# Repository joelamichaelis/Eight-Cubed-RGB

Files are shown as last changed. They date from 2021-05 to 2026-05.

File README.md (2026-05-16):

# Custom 8x8x8 RGB LED Cube

Check out the companion repo: https://github.com/joelamichaelis/8x8x8_RGB_LED_CUBE
It appears that repo was made first.
It appears that I made this repo to try and migrate away from that once since it has a lot of messy firmware builds.

This repository contains my custom 8x8x8 RGB LED cube design/build, which I worked on from late 2018 through early 2020.
This is primarily intended as an archived engineering showcase of the custom hardware, PCB, and firmware work rather than as a polished build guide.

## Context

This is one of my first hobby electronics designs that I consider worth showcasing.

I stopped developing this project years ago. Prior to this 2026 documentation update, the repository contained only a standalone Keil firmware project with no other context.

The firmware is set up as a Keil MDK 5 project, exported from STM32CubeMX. I used Keil because it was the embedded development environment I was familiar with from college at the time. I like Keil, but in later projects, I have generally moved toward STM32CubeIDE and other completely free VS Code/GCC-based workflows. I have not migrated this repository.

The original RGB LED cube was built with a classmate for a one-semester, one-credit senior design class in Fall 2018, shortly before I graduated with my BSEE that December.

After graduating, I was left with a prototype-grade 8x8x8 RGB LED cube wired to prototype-grade electronics on protoboards and hastily connected to a rough Arduino sketch.

I wanted to keep developing the project, which led me to design custom electronics on a custom PCB, paired with custom STM32 firmware that I architected and wrote myself.

I named the custom PCBA the **motherboard** because it is the core electronics piece of the design. The motherboard combines the following circuitry onto a custom PCBA:

- Power supply
- LED power load switches
- STM32F103 Blue Pill microcontroller
- PWM drivers
- LCD
- Capacitive touch scroll wheel and keypad
- Unused ESP8266 RF module
- Supporting level-shifting circuitry

I wanted to gain real embedded system design experience, so I decided to move away from Arduino and use an STM32F103 on a Blue Pill microcontroller platform instead.

At the time, STM32F103 Blue Pill boards were abundant and inexpensive, around $20 for a 10-pack on eBay. The ones I used appeared to be genuine, or at least not poor-quality clones, which is different from what I observed after the COVID-era supply chain disruption.

## Physical Build

The physical build closely followed Steve Manley's RGB LED cube guides.

The key dependencies this project has from Steve's build are his mechanical build and assembly instructions, along with the cube's 9x9-inch base PCB.

The electronics, firmware implementation, and other design choices may have had some inspiration from Steve's and other people's designs, but my intent was to create my own design from scratch.

- Steve Manley's YouTube instructional series: https://www.youtube.com/playlist?app=desktop&list=PL2eohiNrVbjwBBmdMBNiG6VZEHkuPX1jt
- Steve Manley's Dropbox share, where his files and base PCBA have been made publicly available: https://www.dropbox.com/scl/fo/yy7fa9qwqz1qt9lec915d/ANIrxRMUm1n4fHg-VZvry4I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

This part of the project is not the highlight of this repository, but it is still worth documenting. Search the repository for supplemental photos.

My classmate created the mechanical jigs and helped with other parts of the build. I remember spending many nights and evenings bending and trimming individual LEDs with a jig, soldering those LEDs into 1x8 strips with bus wire using a second jig, and then soldering those 1x8 strips into 8x8 vertical panels with a third jig.

The 8x8 vertical panels were then soldered onto a base PCB we ordered. That base PCB adapts the cube's 192 soldered connections into 8 sets of 3x 1x8 header groupings.

Each TLC5940 current PWM driver used in this design controls 16 channels, so 12 daisy-chained PWM drivers map to all of the 1x8 headers.

## Motherboard

Our original senior design implementation required a jumbled mess of custom ribbon cables. The motherboard I designed eliminated the need for those ribbon cables and avoided having prototype electronics crammed under the cube.

Instead, the motherboard cleanly mates female 1x8 headers to the LED cube base's male 1x8 headers.

I also have some 3D-printed mechanical base parts that I intend to include in the repository if possible.

## Project Status / Known Issues

This project is in a functionally mature state with some known bugs, but it is no longer under active development.

Because this work was done several years ago, some files may be rough, incomplete, or not organized to the standard I would use for a current project. The goal of this repository is to preserve and share the project rather than present it as an actively maintained product or polished reference design.

I stopped developing the project after eventually getting bored, wanting to work on other things, or perhaps taking a break to move and then never taking the project out of its tub again.

I consider the core firmware driver and architecture logic to be architecturally mature.

I built a framework in the firmware to accept 3D video, but stopped short of creating a PC program or other tool that would allow animation files to be written and loaded via an SD card or other means.

I quickly learned that the STM32F103's 32K/64K flash was acceptable for simple, algorithmically defined animations, but inadequate for importing and running user-defined custom animations. This led me to realize that I should add an SD card to load and run externally defined animations, although I do not believe I fully developed that feature.

There is a Motherboard Rev2 in this repository. It appears to be functionally coherent, but I do not think I ever ordered those boards. At the time, I was still thinking through other changes I wanted to make, such as adding an SD card so non-hardcoded animations could be loaded without reflashing the LED cube.

As noted on the Rev1 schematic, there are a couple of level-shifter circuits that do not work with the discrete implementation because they are used with high-speed switching signals and the bandwidth of my level-shifter design is insufficient. I reworked my board to fix this.

The Rev2 design, which I never ordered, also addresses this by moving away from the component-heavy discrete level-shifting scheme and using the TXS0108 level-shifter IC, which I have come to prefer.

I remember there being some sort of startup transient that I never fixed. If I had all 8 of the 8x8 LED vertical layers connected to their FET load switches during power-up, all 512 LEDs would light up dimly white-ish. I believe this was some sort of startup transient inducing a brownout. If I ever resurrect development on this project, this would be a high-priority issue to address.

Due to the startup transient bug mentioned above, I made a dummy 8x8 LED array that I used for development without the persistence-of-vision effect of multiplexing all 8 layers.

I spent a lot of time experimenting with different 2D animations and making them accessible through the LCD menu, which can be navigated using the capacitive touch scroll wheel / touchpad.

I remember realizing that the capacitive touch scroll wheel is less useful than the keypad, and that only one of the two is really needed to navigate a menu. I also remember realizing that while it was fun to use this project to experiment with capacitive touch inputs, that part was unnecessary. When my hands got slightly sweaty, it was hard to get the capacitive touch inputs to behave the way I wanted.

Mechanical buttons would have been simpler, although the capacitive touch implementation was fun to experiment with.

A fimrware architectural design doc is missing & warranted.

## Repository Contents

Depending on what has been uploaded, this repository may include:

- PCB design files
- Firmware source code
- Hardware notes
- Photos of the completed cube
- Supporting documentation or design references
- 3D-printed mechanical base parts, if available

## Notes

This repository is provided as-is. It may be useful for reference, inspiration, or as an example of a custom RGB LED cube hardware project, but it should not be assumed to be a drop-in build guide without reviewing the design files and code.

## License

No license has been specified yet.

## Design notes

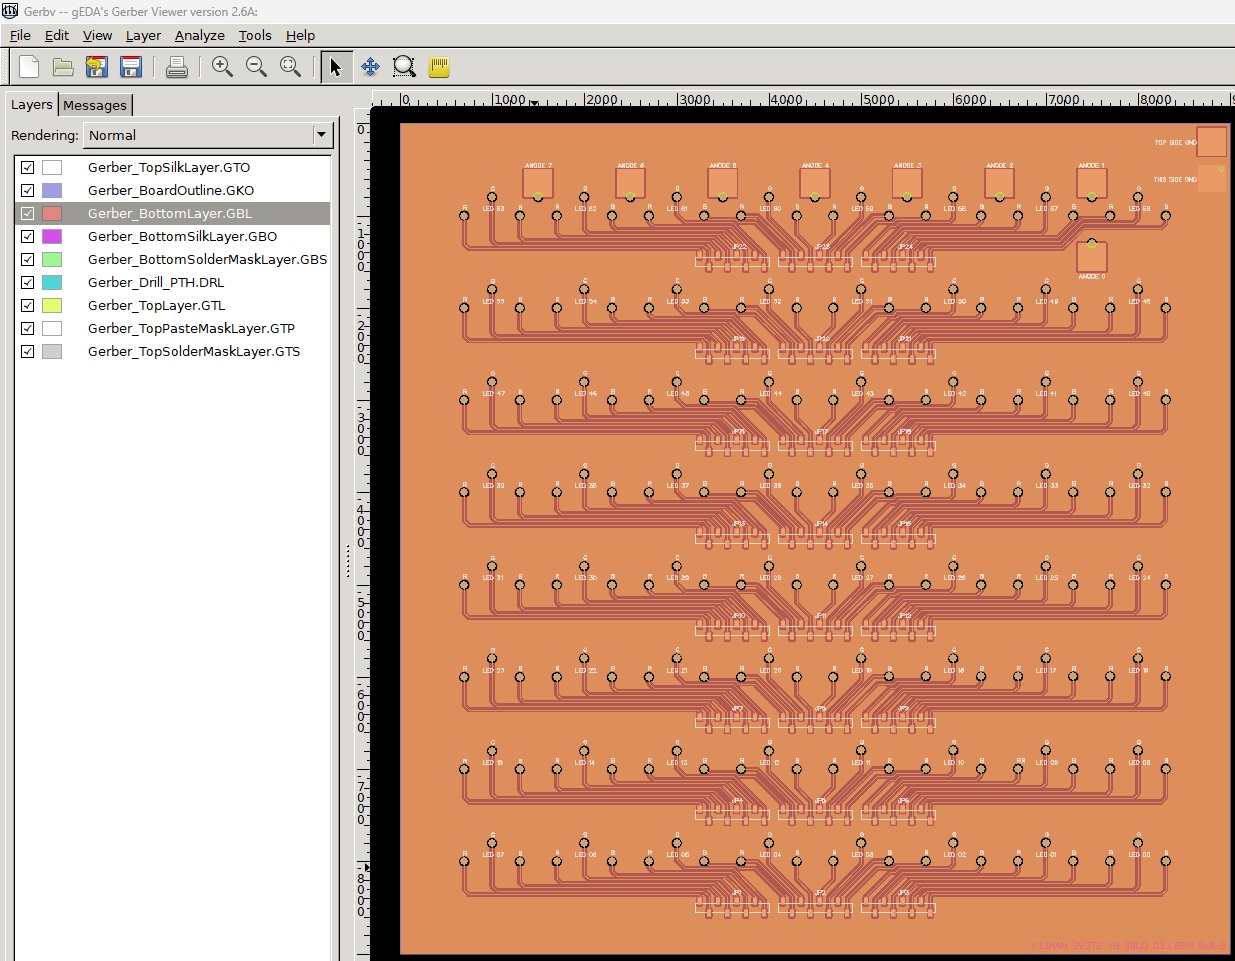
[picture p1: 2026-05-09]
Photos/Manley RGB Cube Base PCB.png

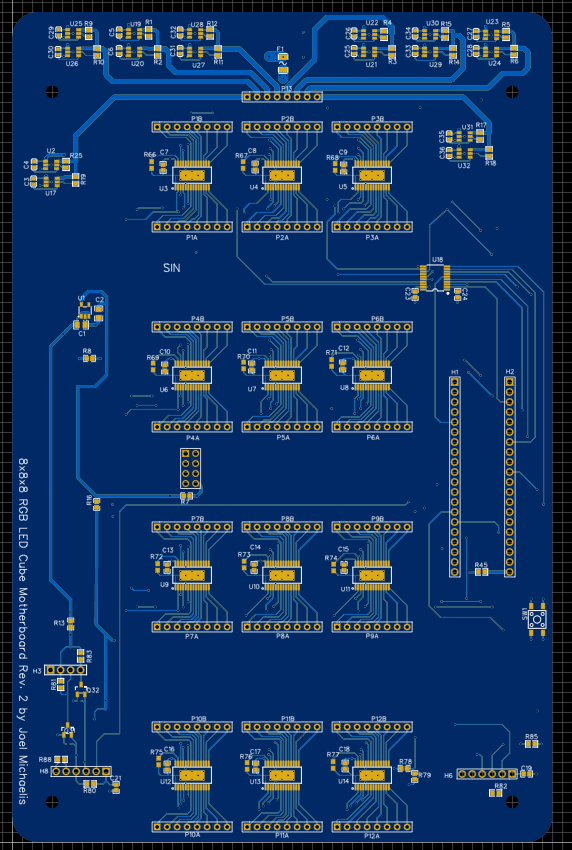
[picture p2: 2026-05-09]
HW/Rev2/Motherboard Rev2 Render.png

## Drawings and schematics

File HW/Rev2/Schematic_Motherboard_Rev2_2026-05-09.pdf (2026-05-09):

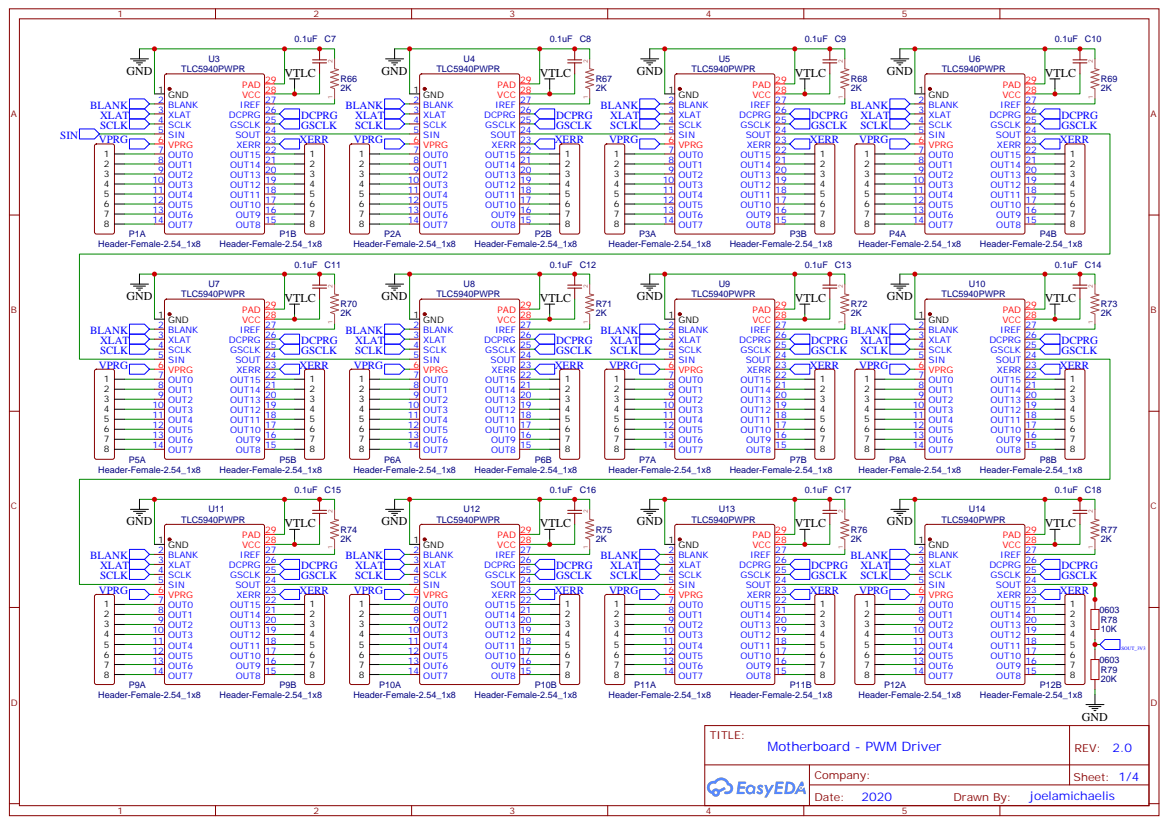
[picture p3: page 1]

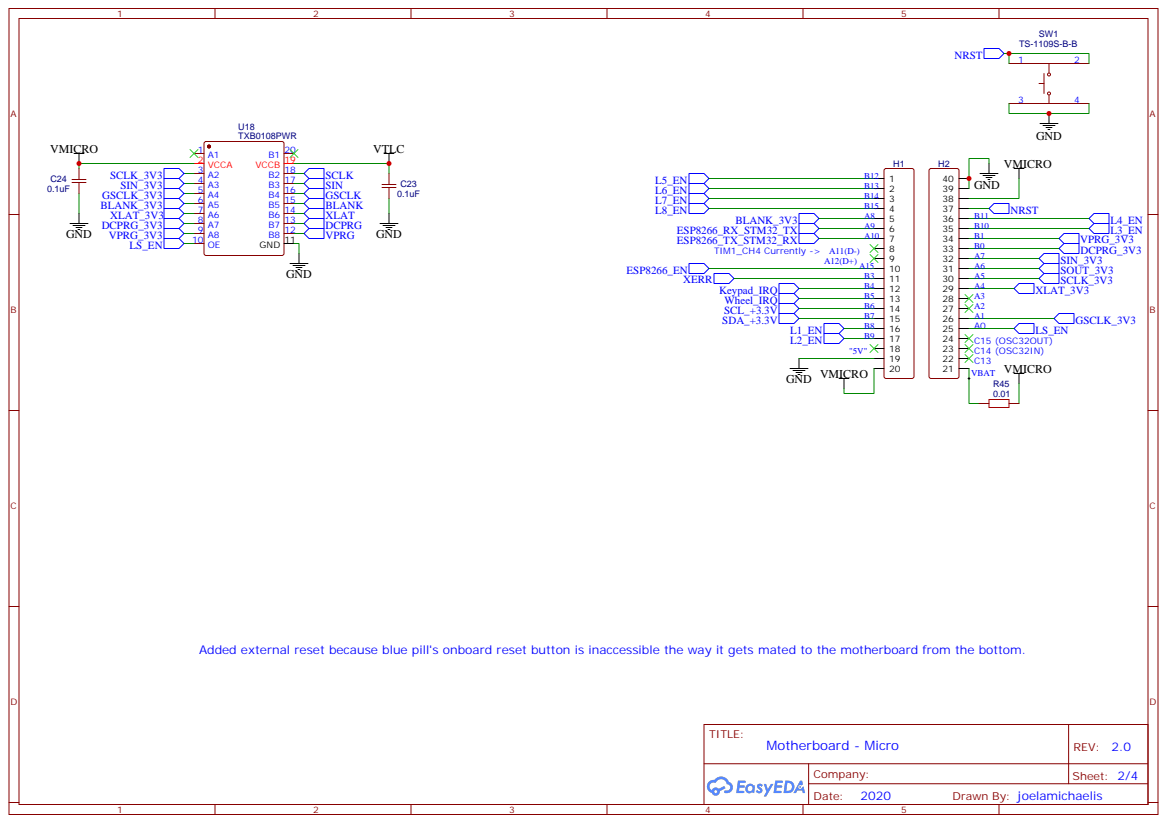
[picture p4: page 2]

Added external reset because blue pill's onboard reset button is inaccessible the way it gets mated to the motherboard from the bottom.

## ESP8266 Connector

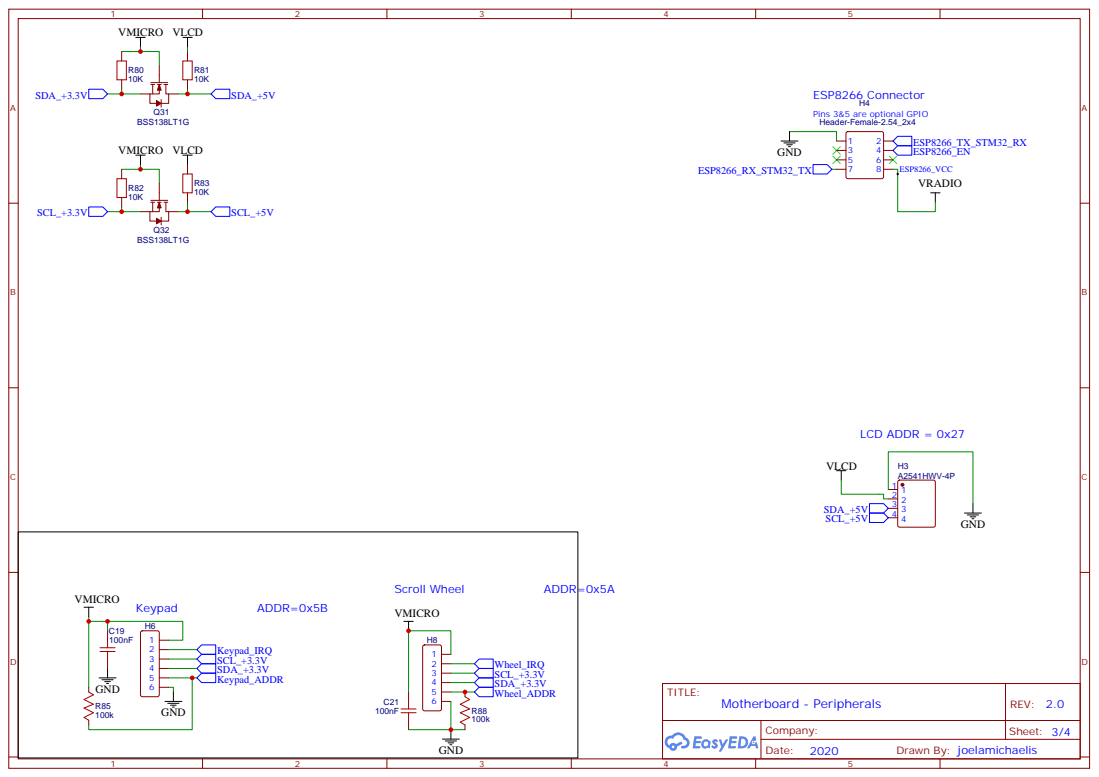
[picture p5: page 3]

Pins 3&5 are optional GPIO
Header-Female-2.54_2x4

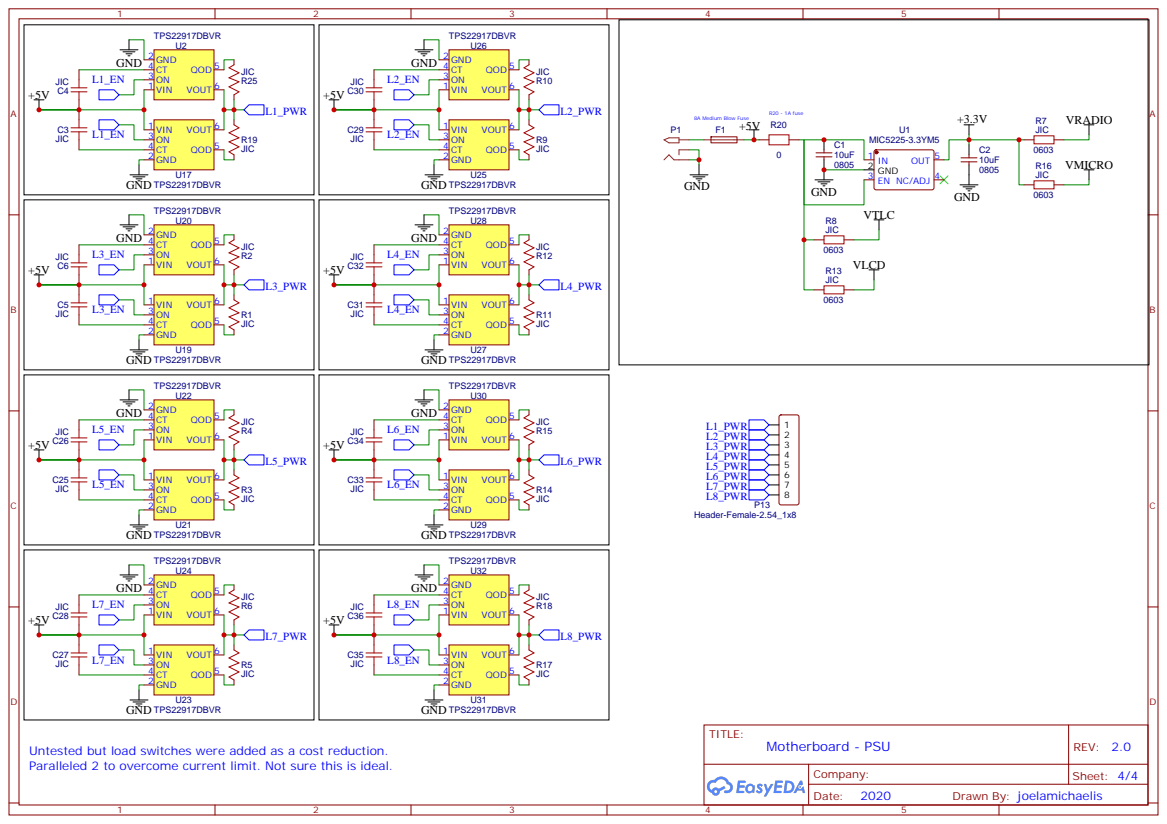
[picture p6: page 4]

Untested but load switches were added as a cost reduction.
Paralleled 2 to overcome current limit. Not sure this is ideal.

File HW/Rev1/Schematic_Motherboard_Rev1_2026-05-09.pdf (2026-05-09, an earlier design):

# LED Power Load Switches Power Supply

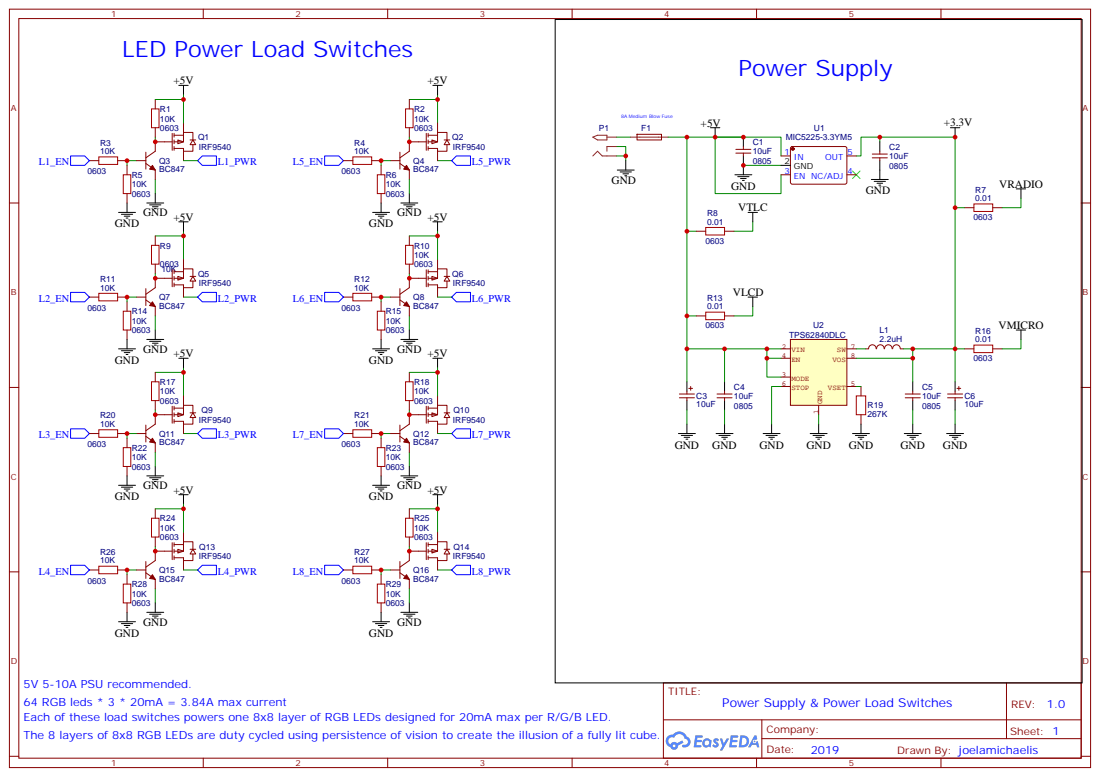
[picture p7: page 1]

5V 5-10A PSU recommended.
64 RGB leds * 3 * 20mA = 3.84A max current
Each of these load switches powers one 8x8 layer of RGB LEDs designed for 20mA max per R/G/B LED.
The 8 layers of 8x8 RGB LEDs are duty cycled using persistence of vision to create the illusion of a fully lit cube.

# PWM Driver - Micro STM32F103 Blue Pill Adapter

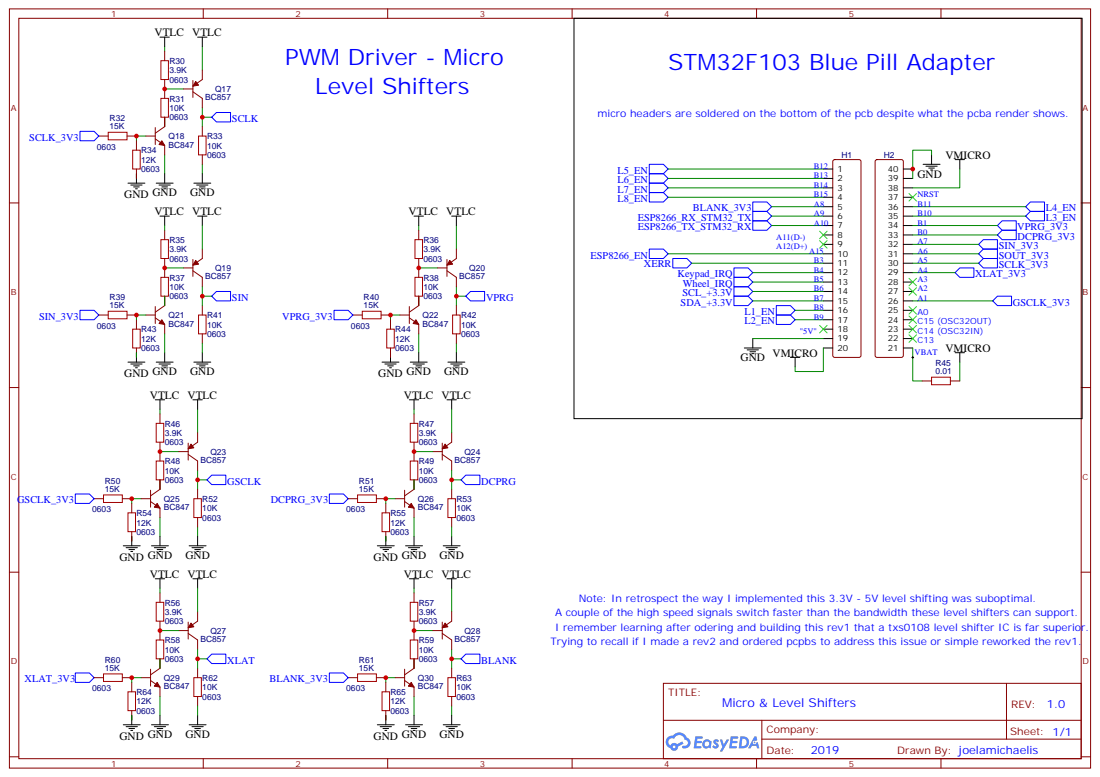
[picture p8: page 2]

micro headers are soldered on the bottom of the pcb despite what the pcba render shows.

Note: In retrospect the way I implemented this 3.3V - 5V level shifting was suboptimal.
A couple of the high speed signals switch faster than the bandwidth these level shifters can support.
I remember learning after odering and building this rev1 that a txs0108 level shifter IC is far superior.
Trying to recall if I made a rev2 and ordered pcpbs to address this issue or simple reworked the rev1.

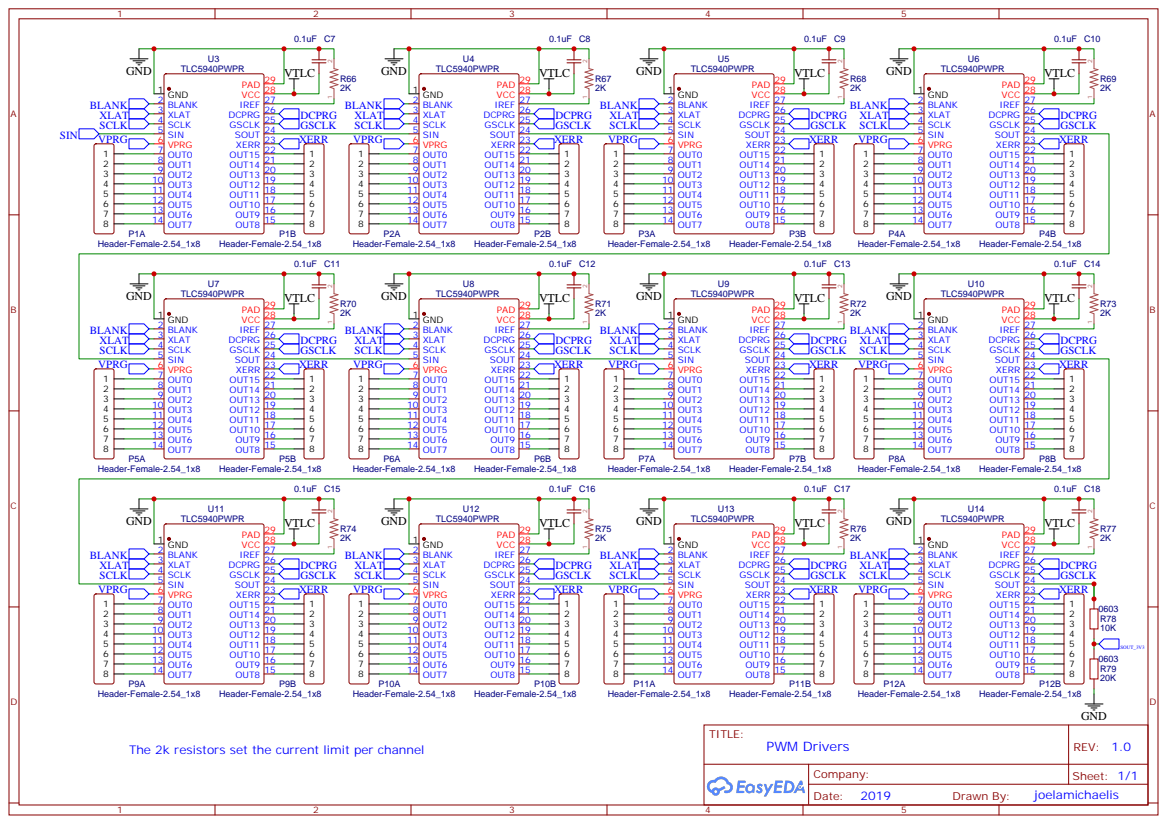
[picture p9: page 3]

The 2k resistors set the current limit per channel

## LCD ADDR = 0x27

## ESP8266 Connector

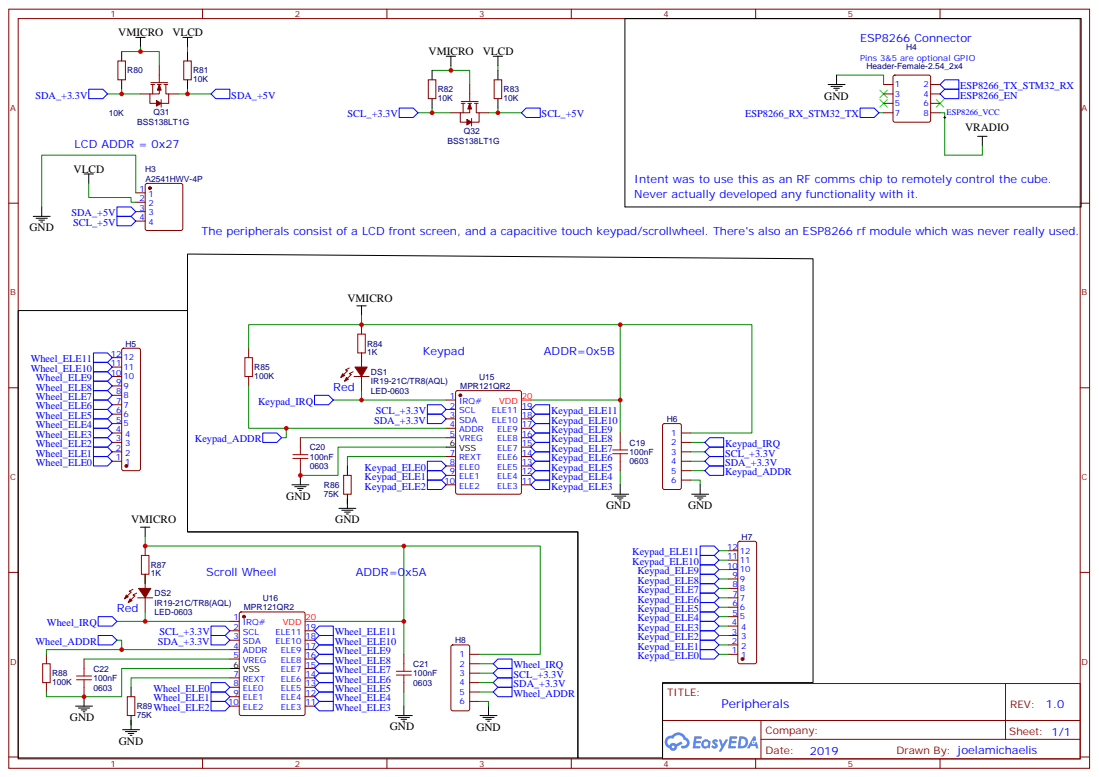
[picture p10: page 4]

Pins 3&5 are optional GPIO
Header-Female-2.54_2x4

Intent was to use this as an RF comms chip to remotely control the cube.
Never actually developed any functionality with it.

The peripherals consist of a LCD front screen, and a capacitive touch keypad/scrollwheel. There's also an ESP8266 rf module which was never really used.

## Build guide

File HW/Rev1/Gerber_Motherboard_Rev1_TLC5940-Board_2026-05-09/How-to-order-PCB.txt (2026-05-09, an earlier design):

How to Order PCB

Please refer to:
https://docs.easyeda.com/en/PCB/Order-PCB

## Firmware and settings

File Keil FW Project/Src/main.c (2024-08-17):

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

/* Includes ------------------------------------------------------------------*/
#include "main.h"

/* USER CODE BEGIN Includes */
//#include <stdbool.h>
/* USER CODE END Includes */

/* USER CODE BEGIN PD */
#define NUM_TLCS 12
#define UART_TIMEOUT 500 //ms
/* USER CODE END PD */

I2C_HandleTypeDef hi2c1;

RTC_HandleTypeDef hrtc;

SPI_HandleTypeDef hspi1;

TIM_HandleTypeDef htim1;
TIM_HandleTypeDef htim2;

UART_HandleTypeDef huart1;

void SystemClock_Config(void);
static void MX_GPIO_Init(void);
static void MX_I2C1_Init(void);
static void MX_RTC_Init(void);
static void MX_SPI1_Init(void);
static void MX_TIM1_Init(void);
static void MX_TIM2_Init(void);
static void MX_USART1_UART_Init(void);
/* USER CODE BEGIN PFP */
void previous_lyr_off(uint16_t activeLyr);
uint16_t current_lyr_on(uint16_t activeLyr);
/* USER CODE END PFP */

/* USER CODE BEGIN 0 */

bool UPDATE_FRAME = 0;
bool commandReceived = 0;
bool initialLyrToggle = 1;

//Indicates active cube layer, must be global so timer IRQ can access.
uint8_t activeLyr = 0;
uint8_t uartRxIndex = 0;

//Data Arrays & Pointers shese should probably not be global
// Data Arrays
uint16_t data16[16*NUM_TLCS];
uint8_t data8[24*NUM_TLCS];

// Data Pointers
uint16_t *data16Ptr = &data16[0];
uint8_t *data8Ptr = &data8[0];										

// pin mapping - this should never need to be reconfigured now that all the cabling as been eliminated :^)
// could make const uint8_ts but saving space in flash
uint8_t redMap[64] = {178,181,160,163,166,145,148,151,189,186,175,172,169,158,155,152,130,133,112,115,118,97,100,103,141,138,127,124,121,110,107,104,82,85,64,67,70,49,52,55,93,90,79,76,73,62,59,56,34,37,16,19,22,1,4,7,45,42,31,28,25,14,11,8};
uint8_t grnMap[64] = {177,180,183,162,165,144,147,150,190,187,184,173,170,159,156,153,129,132,135,114,117,96,99,102,142,139,136,125,122,111,108,105,81,84,87,66,69,48,51,54,94,91,88,77,74,63,60,57,33,36,39,18,21,0,3,6,46,43,40,29,26,15,12,9};
uint8_t bluMap[64] = {176,179,182,161,164,167,146,149,191,188,185,174,171,168,157,154,128,131,134,113,116,119,98,101,143,140,137,126,123,120,109,106,80,83,86,65,68,71,50,53,95,92,89,78,75,72,61,58,32,35,38,17,20,23,2,5,47,44,41,30,27,24,13,10};

uint8_t uartTxBuffer[DEF_STR_LEN];
uint8_t uartRxBuffer[RAW_CLI_DATA_STR_LEN];

Frame_TypeDef frame;
Frame_TypeDef *framePtr;

	
	
cliData_TypeDef cliData;
cliData_TypeDef *cliDataPtr = &cliData;
		
/* USER CODE END 0 */

/**
  * @brief  The application entry point.
  * @retval int
  */
int main(void)
{
  /* MCU Configuration--------------------------------------------------------*/

  /* Reset of all peripherals, Initializes the Flash interface and the Systick. */
  HAL_Init();

  /* Configure the system clock */
  SystemClock_Config();

  /* Initialize all configured peripherals */
  MX_GPIO_Init();
  MX_I2C1_Init();
  MX_RTC_Init();
  MX_SPI1_Init();
  MX_TIM1_Init();
  MX_TIM2_Init();
  MX_USART1_UART_Init();
  /* USER CODE BEGIN 2 */
	
	
	HAL_TIM_OC_Start(&htim2, TIM_CHANNEL_2);	//
	HAL_TIM_Base_Start_IT(&htim1);
	HAL_TIM_OC_Start(&htim1, TIM_CHANNEL_4);	//this was working with ch1 even though thats set as a gpio!
	HAL_SPI_Init(&hspi1);
	tlc_clear(data16Ptr);
	UPDATE_FRAME = 1;
	
	
	//have to manually initialize pointers 
	framePtr = &frame;
	frame.lyr0Ptr = &frame.lyr0;
	frame.lyr1Ptr = &frame.lyr1;
	frame.lyr2Ptr = &frame.lyr2;
	frame.lyr3Ptr = &frame.lyr3;
	frame.lyr4Ptr = &frame.lyr4;
	frame.lyr5Ptr = &frame.lyr5;
	frame.lyr6Ptr = &frame.lyr6;
	frame.lyr7Ptr = &frame.lyr7;
	frame.lyr0.redArrPtr = &frame.lyr0.redArray[0];
	frame.lyr0.grnArrPtr = &frame.lyr0.grnArray[0];
	frame.lyr0.bluArrPtr = &frame.lyr0.bluArray[0];
	frame.lyr1.redArrPtr = &frame.lyr1.redArray[0];
	frame.lyr1.grnArrPtr = &frame.lyr1.grnArray[0];
	frame.lyr1.bluArrPtr = &frame.lyr1.bluArray[0];
	frame.lyr2.redArrPtr = &frame.lyr2.redArray[0];
	frame.lyr2.grnArrPtr = &frame.lyr2.grnArray[0];
	frame.lyr2.bluArrPtr = &frame.lyr2.bluArray[0];
	frame.lyr3.redArrPtr = &frame.lyr3.redArray[0];
	frame.lyr3.grnArrPtr = &frame.lyr3.grnArray[0];
	frame.lyr3.bluArrPtr = &frame.lyr3.bluArray[0];
	frame.lyr4.redArrPtr = &frame.lyr4.redArray[0];
	frame.lyr4.grnArrPtr = &frame.lyr4.grnArray[0];
	frame.lyr4.bluArrPtr = &frame.lyr4.bluArray[0];
	frame.lyr5.redArrPtr = &frame.lyr5.redArray[0];
	frame.lyr5.grnArrPtr = &frame.lyr5.grnArray[0];
	frame.lyr5.bluArrPtr = &frame.lyr5.bluArray[0];
	frame.lyr6.redArrPtr = &frame.lyr6.redArray[0];
	frame.lyr6.grnArrPtr = &frame.lyr6.grnArray[0];
	frame.lyr6.bluArrPtr = &frame.lyr6.bluArray[0];
	frame.lyr7.redArrPtr = &frame.lyr7.redArray[0];
	frame.lyr7.grnArrPtr = &frame.lyr7.grnArray[0];
	frame.lyr7.bluArrPtr = &frame.lyr7.bluArray[0];
	
	HAL_UART_Receive_IT(&huart1, &cliData.rawTextInput[uartRxIndex], 1);
	//frame_set_single_led_color(framePtr,0,0x0FFF0FFF0FFF,45);
	for(uint8_t jk=0;jk<64;jk++)
	{
		lyr_frame_set_single_led_color(frame.lyr0Ptr, 0x0FFF0FFF0FFF, jk);
	}
	
	UPDATE_FRAME = true;
	HAL_Delay(1000);
	
	lcd20x4_i2c_init(&hi2c1);
	lcd20x4_i2c_clear();
	lcd20x4_i2c_1stLine();
	lcd20x4_i2c_printf("8^3 RGB Begin!");
	
  /* USER CODE END 2 */

  /* Infinite loop */
  /* USER CODE BEGIN WHILE */
  while (1)
  {
		if(commandReceived==true)
		{
			commandReceived = false;
			cli_parse_data(cliDataPtr);
			cli_interpret_data(cliDataPtr,framePtr);
			cli_formulate_response(cliDataPtr);
			if(cliData.responseEnum != Null) HAL_UART_Transmit(&huart1, &cliData.responseStr[0], cliData.responseLen, UART_TIMEOUT);
			cli_data_cleanse(cliDataPtr); // resets everything except the rawTextInput
		}
		HAL_Delay(10);
	}
    /* USER CODE END WHILE */

}

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
/* USER CODE BEGIN 4 */
void HAL_GPIO_EXTI_Callback(uint16_t GPIO_Pin)
{	
	/*
	currentAction = Menu_Read_MPR121(hi2c1, GPIO_Pin, currentAction);
	if (currentAction == ACTION_HALT_ANIMATION) HALT_ANIMATION = true;
	*/
}

void HAL_TIM_PeriodElapsedCallback(TIM_HandleTypeDef *htim)
{	
	
	if(initialLyrToggle == true)	//necessary because algorithm wasn't designed to handle inital condition where all lyrs are off
	{	
		initialLyrToggle = false;
		previous_lyr_off(activeLyr);
	}
	
	if(UPDATE_FRAME==0)
	{
		previous_lyr_off(activeLyr);
		HAL_GPIO_WritePin(BLANK_3V3_GPIO_Port, BLANK_3V3_Pin, GPIO_PIN_SET);
		for(uint16_t dummyVar =1;dummyVar<15;dummyVar++); // short delay (approx 3us)
		HAL_GPIO_WritePin(BLANK_3V3_GPIO_Port, BLANK_3V3_Pin, GPIO_PIN_RESET);
		activeLyr =  current_lyr_on(activeLyr);
		return;
	}
	
	if(UPDATE_FRAME==1)
	{
		previous_lyr_off(activeLyr);
		lyr_frame_convert(frame.lyr0,data16Ptr); //previous usage
		//frame_convert(frame,activeLyr,data16Ptr);
		tlc_spi_convert(data16Ptr, data8Ptr);
		HAL_SPI_Transmit(&hspi1, data8Ptr, 24*NUM_TLCS, 10);
		HAL_GPIO_WritePin(BLANK_3V3_GPIO_Port, BLANK_3V3_Pin, GPIO_PIN_SET);
		HAL_GPIO_WritePin(XLAT_3V3_GPIO_Port, XLAT_3V3_Pin, GPIO_PIN_SET);
		for(uint16_t dummyVar =1;dummyVar<15;dummyVar++); // short delay (approx 3us)
		HAL_GPIO_WritePin(XLAT_3V3_GPIO_Port, XLAT_3V3_Pin, GPIO_PIN_RESET);
		HAL_GPIO_WritePin(BLANK_3V3_GPIO_Port, BLANK_3V3_Pin, GPIO_PIN_RESET);
		UPDATE_FRAME=0;
		activeLyr =  current_lyr_on(activeLyr);
		return;
	}
}
	
void previous_lyr_off(uint16_t activeLyr)
{
	if(activeLyr == 0) HAL_GPIO_TogglePin(L8_EN_GPIO_Port, L8_EN_Pin);
	if(activeLyr == 1) HAL_GPIO_TogglePin(L1_EN_GPIO_Port, L1_EN_Pin);
	if(activeLyr == 2) HAL_GPIO_TogglePin(L2_EN_GPIO_Port, L2_EN_Pin);
	if(activeLyr == 3) HAL_GPIO_TogglePin(L3_EN_GPIO_Port, L3_EN_Pin);
	if(activeLyr == 4) HAL_GPIO_TogglePin(L4_EN_GPIO_Port, L4_EN_Pin);
	if(activeLyr == 5) HAL_GPIO_TogglePin(L5_EN_GPIO_Port, L5_EN_Pin);
	if(activeLyr == 6) HAL_GPIO_TogglePin(L6_EN_GPIO_Port, L6_EN_Pin);
	if(activeLyr == 7) HAL_GPIO_TogglePin(L7_EN_GPIO_Port, L7_EN_Pin);
}
	
uint16_t current_lyr_on(uint16_t activeLyr)
{
	if(activeLyr == 0) HAL_GPIO_TogglePin(L1_EN_GPIO_Port, L1_EN_Pin);
	if(activeLyr == 1) HAL_GPIO_TogglePin(L2_EN_GPIO_Port, L2_EN_Pin);
	if(activeLyr == 2) HAL_GPIO_TogglePin(L3_EN_GPIO_Port, L3_EN_Pin);
	if(activeLyr == 3) HAL_GPIO_TogglePin(L4_EN_GPIO_Port, L4_EN_Pin);
	if(activeLyr == 4) HAL_GPIO_TogglePin(L5_EN_GPIO_Port, L5_EN_Pin);
	if(activeLyr == 5) HAL_GPIO_TogglePin(L6_EN_GPIO_Port, L6_EN_Pin);
	if(activeLyr == 6) HAL_GPIO_TogglePin(L7_EN_GPIO_Port, L7_EN_Pin);
	if(activeLyr == 7) HAL_GPIO_TogglePin(L8_EN_GPIO_Port, L8_EN_Pin);
	activeLyr++;
	if(activeLyr==8) activeLyr = 0;
	return activeLyr;
}

void HAL_UART_RxCpltCallback(UART_HandleTypeDef *huart)
{
	if(cliData.rawTextInput[uartRxIndex] == '\n') 
	{
		commandReceived = true;
		uartRxIndex = 0;
	}
	
	else uartRxIndex++;
	
	HAL_UART_Receive_IT(&huart1, &cliData.rawTextInput[uartRxIndex], 1);
}

/* USER CODE END 4 */
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


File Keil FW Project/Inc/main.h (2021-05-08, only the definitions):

#define GSCK_3V3_Pin GPIO_PIN_1
#define GSCK_3V3_GPIO_Port GPIOA
#define XLAT_3V3_Pin GPIO_PIN_4
#define XLAT_3V3_GPIO_Port GPIOA
#define SCLK_3V3_Pin GPIO_PIN_5
#define SCLK_3V3_GPIO_Port GPIOA
#define SOUT_3V3_Pin GPIO_PIN_6
#define SOUT_3V3_GPIO_Port GPIOA
#define SIN_3V3_Pin GPIO_PIN_7
#define SIN_3V3_GPIO_Port GPIOA
#define DCPRG_3V3_Pin GPIO_PIN_0
#define DCPRG_3V3_GPIO_Port GPIOB
#define VPRG_3V3_Pin GPIO_PIN_1
#define VPRG_3V3_GPIO_Port GPIOB
#define L3_EN_Pin GPIO_PIN_10
#define L3_EN_GPIO_Port GPIOB
#define L4_EN_Pin GPIO_PIN_11
#define L4_EN_GPIO_Port GPIOB
#define L5_EN_Pin GPIO_PIN_12
#define L5_EN_GPIO_Port GPIOB
#define L6_EN_Pin GPIO_PIN_13
#define L6_EN_GPIO_Port GPIOB
#define L7_EN_Pin GPIO_PIN_14
#define L7_EN_GPIO_Port GPIOB
#define L8_EN_Pin GPIO_PIN_15
#define L8_EN_GPIO_Port GPIOB
#define BLANK_3V3_Pin GPIO_PIN_8
#define BLANK_3V3_GPIO_Port GPIOA
#define ESP8266_RX_STM32_TX_Pin GPIO_PIN_9
#define ESP8266_RX_STM32_TX_GPIO_Port GPIOA
#define ESP8266_TX_STM32_RX_Pin GPIO_PIN_10
#define ESP8266_TX_STM32_RX_GPIO_Port GPIOA
#define ESP8266_EN_Pin GPIO_PIN_15
#define ESP8266_EN_GPIO_Port GPIOA
#define XERR_Pin GPIO_PIN_3
#define XERR_GPIO_Port GPIOB
#define Keypad_IRQ_Pin GPIO_PIN_4
#define Keypad_IRQ_GPIO_Port GPIOB
#define Keypad_IRQ_EXTI_IRQn EXTI4_IRQn
#define Wheel_IRQ_Pin GPIO_PIN_5
#define Wheel_IRQ_GPIO_Port GPIOB
#define Wheel_IRQ_EXTI_IRQn EXTI9_5_IRQn
#define L1_EN_Pin GPIO_PIN_8
#define L1_EN_GPIO_Port GPIOB
#define L2_EN_Pin GPIO_PIN_9
#define L2_EN_GPIO_Port GPIOB

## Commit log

2021-05-15 committing before modifying cubeMX file for UART interrupt JIC
2026-05-09 archive documentation update, still should add some further photos & supplemental mechanical files.
    [Drill_PTH_Through.DRL, Drill_PTH_Through_Via.DRL, Gerber_BoardOutlineLayer.GKO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]

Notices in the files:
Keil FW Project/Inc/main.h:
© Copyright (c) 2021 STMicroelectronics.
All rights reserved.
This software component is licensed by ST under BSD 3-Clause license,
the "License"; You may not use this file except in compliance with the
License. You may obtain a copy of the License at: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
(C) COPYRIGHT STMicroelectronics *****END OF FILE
